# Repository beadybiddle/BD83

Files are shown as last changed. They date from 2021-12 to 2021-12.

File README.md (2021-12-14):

# BD83
A fully custom 83 Key mechanical keyboard designed around the way that I type. I intend to be able to say that this is truly a keyboard customized to my liking.
The original motivation behind this project was just a frustration at standard ANSI layouts. This project features custom everything, including PCB, plate, case, firmware, and eventually keycaps. Before creating anything, I initially just filmed my hands typing and gaming for an hour to figure out my own tendencies and key usage.

### Layout changes:
- Space bar is shrunk and split because nobody needs six keys' worth of real estate to hit one button.
- Backspace is shrunk because I don't intend to use it there. I've added a secondary backspace between the space bars.
- Caps lock is useless. I've removed it.
- Right shift is useless. I've removed it.
- Numpad function is incorporated into the FN layer on the lefthand side.
- Nav cluster has been moved around the arrow keys so it's easier and more intuitive to navigate code with home/end.
- F13 is now a thing because I had room for it.

### Hardware
There are three main custom hardware components to this keyboard:
- PCB, self explanatory
- Plate, the layer that the keyswitches clip into
- Case, the pieces that house the rest of the board

#### Plate
Keyboards don't necessarily need a plate, but for a myriad of reasons it made sense for me to use one. The plate is 0.06" 304 stainless steel, making it unyielding which is better for linear switch typefeel. I generated a template in swillKB then modeled the plate in Fusion360. Using the DXF exported from Fusion, I waterjet cut the plate.
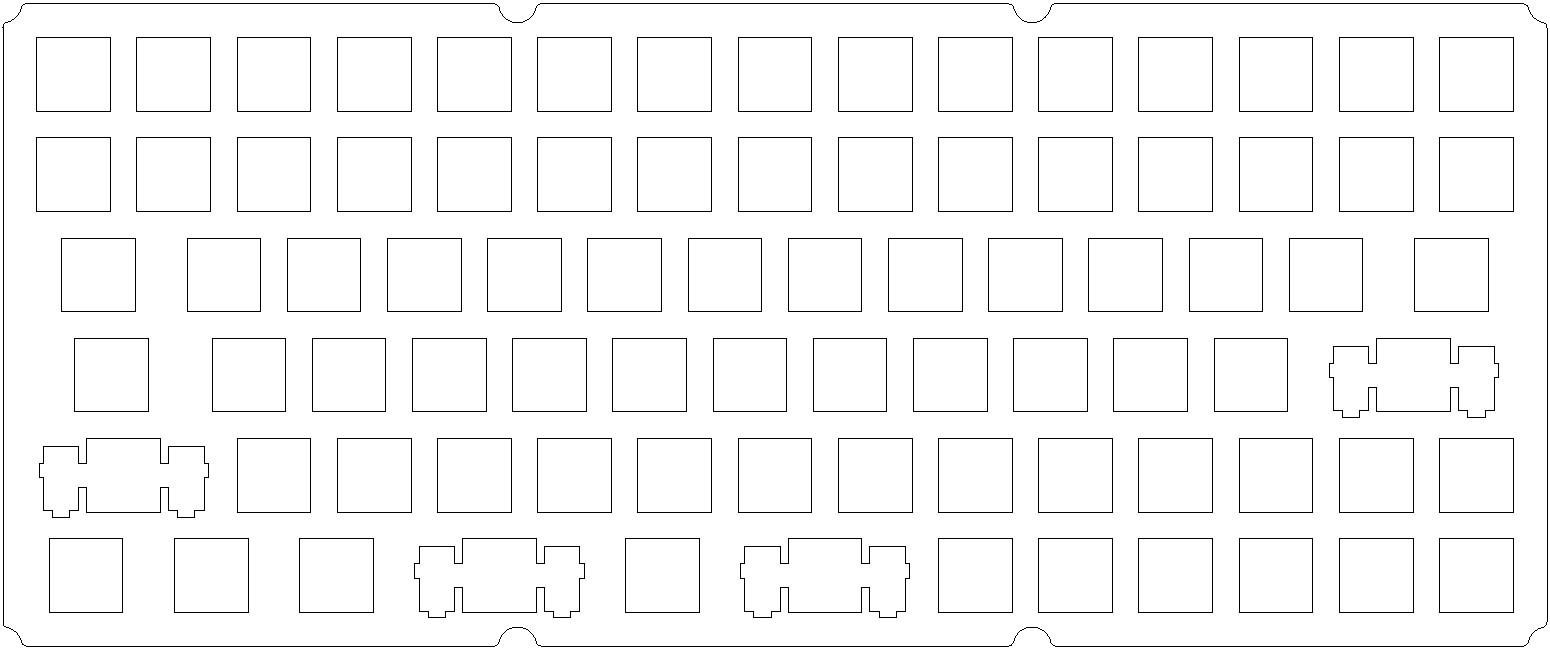
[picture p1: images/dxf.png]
DXF

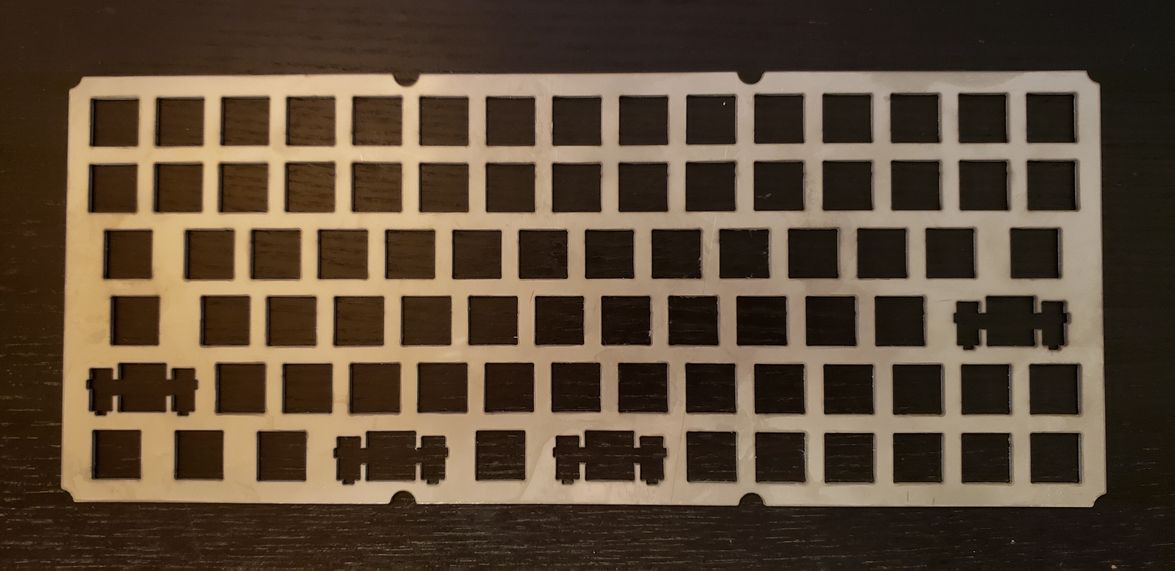
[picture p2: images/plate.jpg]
Plate


#### Case
I've designed two cases, one which is full-sized and intended to be printed on a Form 3L SLA printer at the GaTech Invention Studio, and another which is minimal (hardly qualifying as a case) that I printed on my Voxelab Aquila. All outward-facing edges are chamfered or filleted to look nice and not hurt the flesh. On the back is a hole for a USB-C adapter dongle to poke through. The underside features a pretty beadybiddle logo and some rubber feet made from EPDM rubber bands. I also designed a wrist rest to be extra, but I've made the case so slim that it's not necessary.
I was unable to get access to the Form 3L before the studio closed for the year.
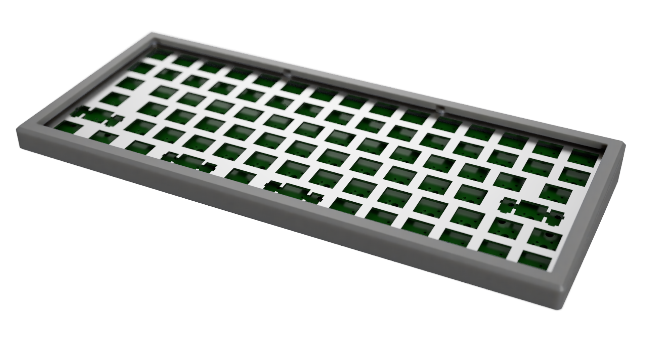
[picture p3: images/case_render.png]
Case
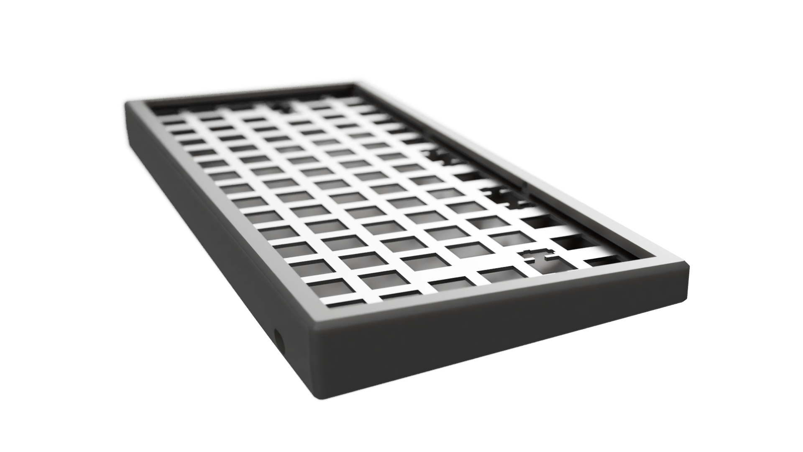
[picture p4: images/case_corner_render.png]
Case Corner
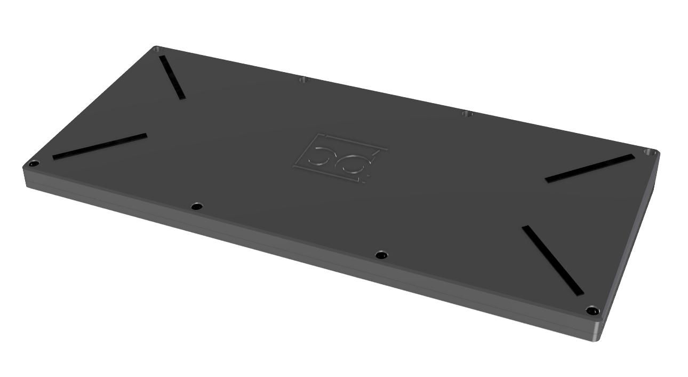
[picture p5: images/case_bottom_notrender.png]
Case Underside
  

The two halves of the case are fastened by eight M3x10 machine screws and nuts around the perimeter. The plate has flanges around the edges that allow it to be sandwiched between these two halves, cushioned by strips of EPDM to dampen the sound and make the typefeel just a little springy. The interior of the case has only 0.8mm of wiggle room to the dangling PCB, making it literally as compact as possible. It is angled five degrees so that the front height is minimized while making room for the Feather board and batteries in the back.
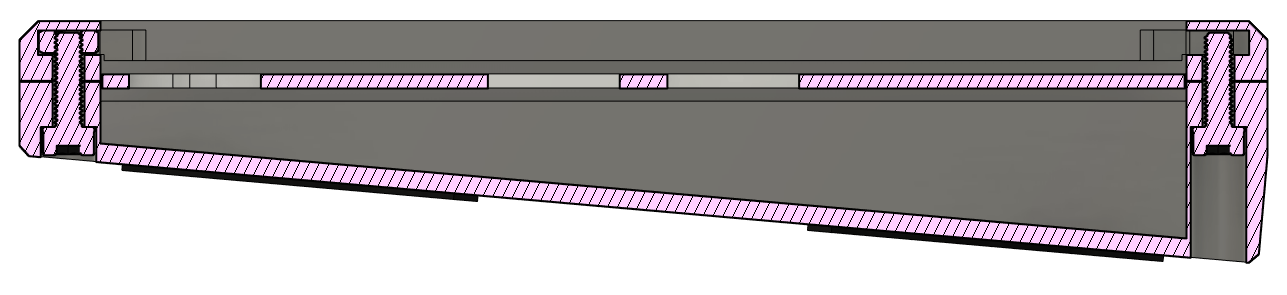
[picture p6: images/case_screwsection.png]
Fastener Assembly
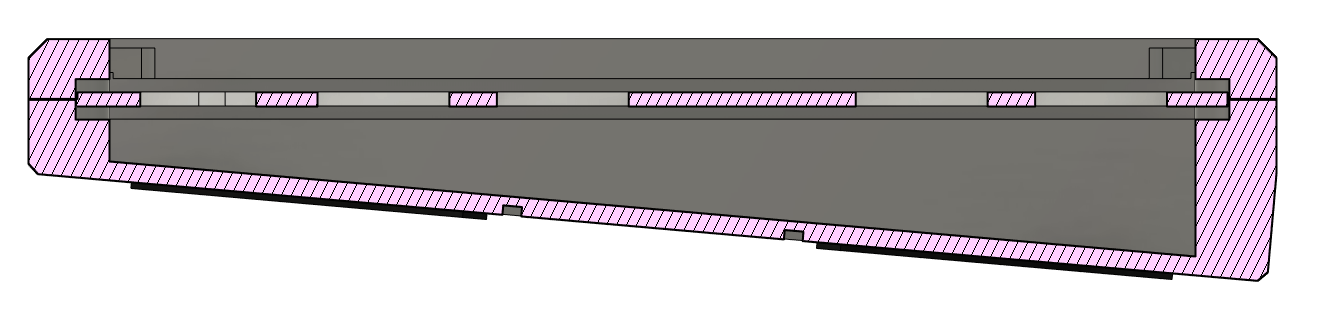
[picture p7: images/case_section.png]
Plate Sandwich
 

The minimal "case" is actually four feet that clip onto the plate and are secured by a single large band. It has the same five degree inclination as the full case so that the electronics won't touch the desk surface. The open design leaves the switches and PCB accessible.
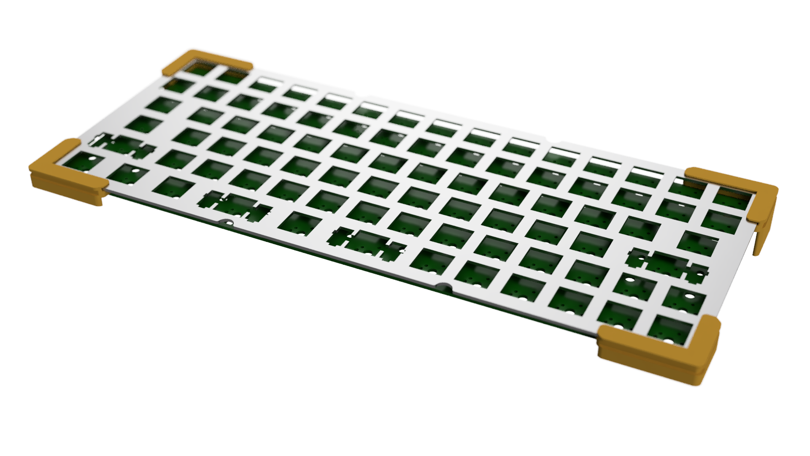
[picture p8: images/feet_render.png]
Feet


#### PCB
The PCB took the longest of all the components (maybe because I'd never made one before) but I'll try to keep it brief here:
I made it to support three main features: bluetooth, RGB lighting, and some level of expandability.
The brains of the board is an Adafruit Feather 32u4 Bluefruit LE, which is a devboard with an intregated nRF51822 BLE module. It also handles LiPo power for going completely wireless.
The LEDs are common-anode RGB packages, and are controlled by two IS31FL3733B drivers. The MCU talks to these drivers via I2C. I was originally planning to use a string of WS2812Bs or SK6812Es, but these have a substantially higher power draw than the ISSI scanning matrix drivers.
There are only 20 GPIO pins on the Feather, though, and several are already used for SPI with the BLE module. In order to accomodate my ideal 83 keys, it would take at least 19 pins to connect all the switches even with matrix duplexing, a number that I couldn't muster while dedicating three to the LED drivers. To get get some extra GPIO, I use an MCP23017 I2C I/O expander. This communicates on the same I2C lines as the ISSI drivers, and creates an additional 16 GPIO pins - more than enough for the rest of the switch matrix.

Diodes are placed between each switch and its corresponding row to prevent ghosting as the matrix is scanned.
VCC is fed through decoupling caps as needed to the slave chips; decoupling around the MCU is already handled by the Feather board.
The address pins on the three I2C chips have solder bridges for customizing the addresses if more devices are added.
A SPDT switch controls the 3V3 regulator enable pin so that power can be controlled, especially when going wireless.
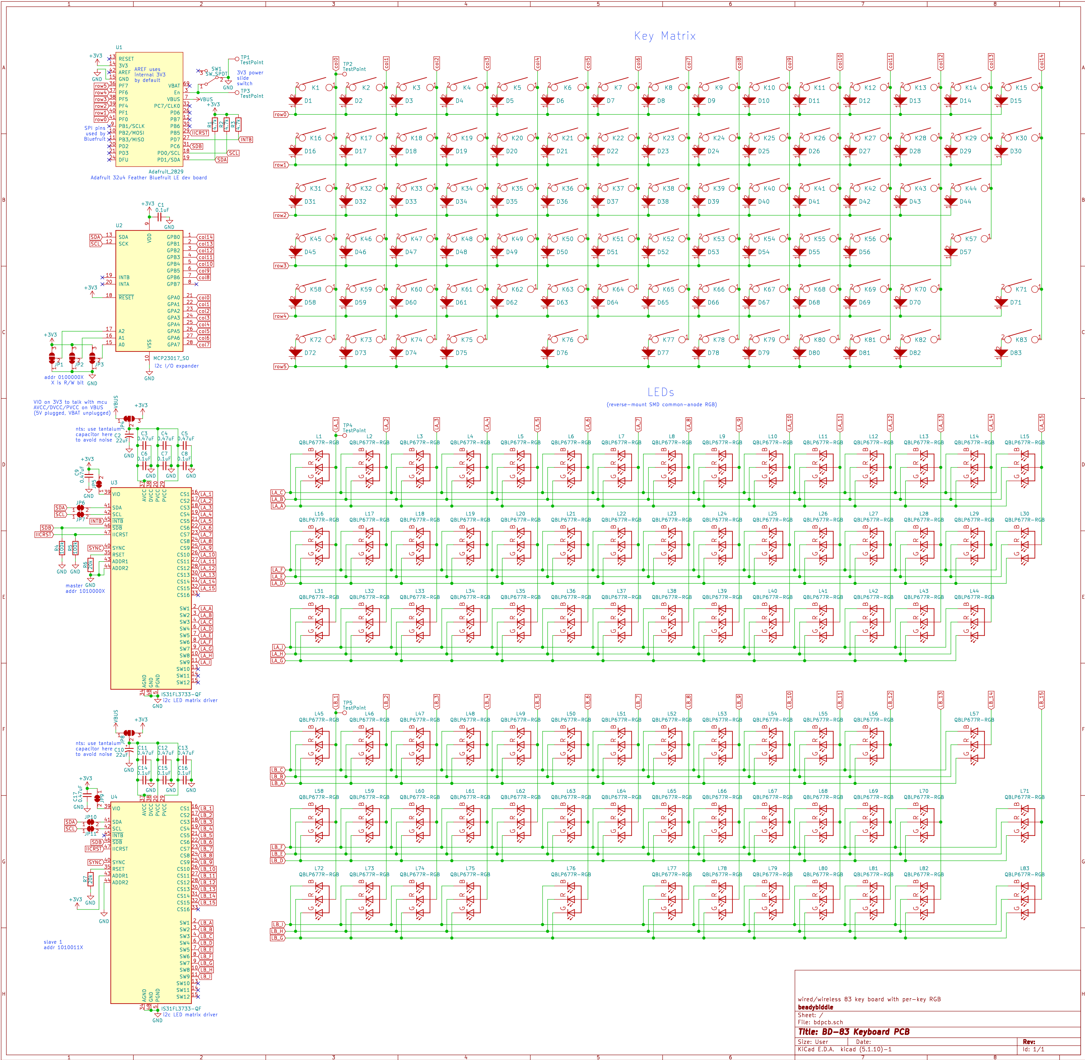
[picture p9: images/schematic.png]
Schematic


The PCB was definitely the most fun part of this whole project; learning to make something so different from what I'm used to was nice.
I routed all of the traces twice because after getting an understanding and making some messy paths the first time it was much easier to organize the rats nest from scratch.
I also went through several iterations of component placements in the process in order to make room for the traces and switches. Most keyboards have plenty of free real estate behind their big spacebars or above the arrow keys, but my compact layout meant everything had to be crammed in tight gaps.
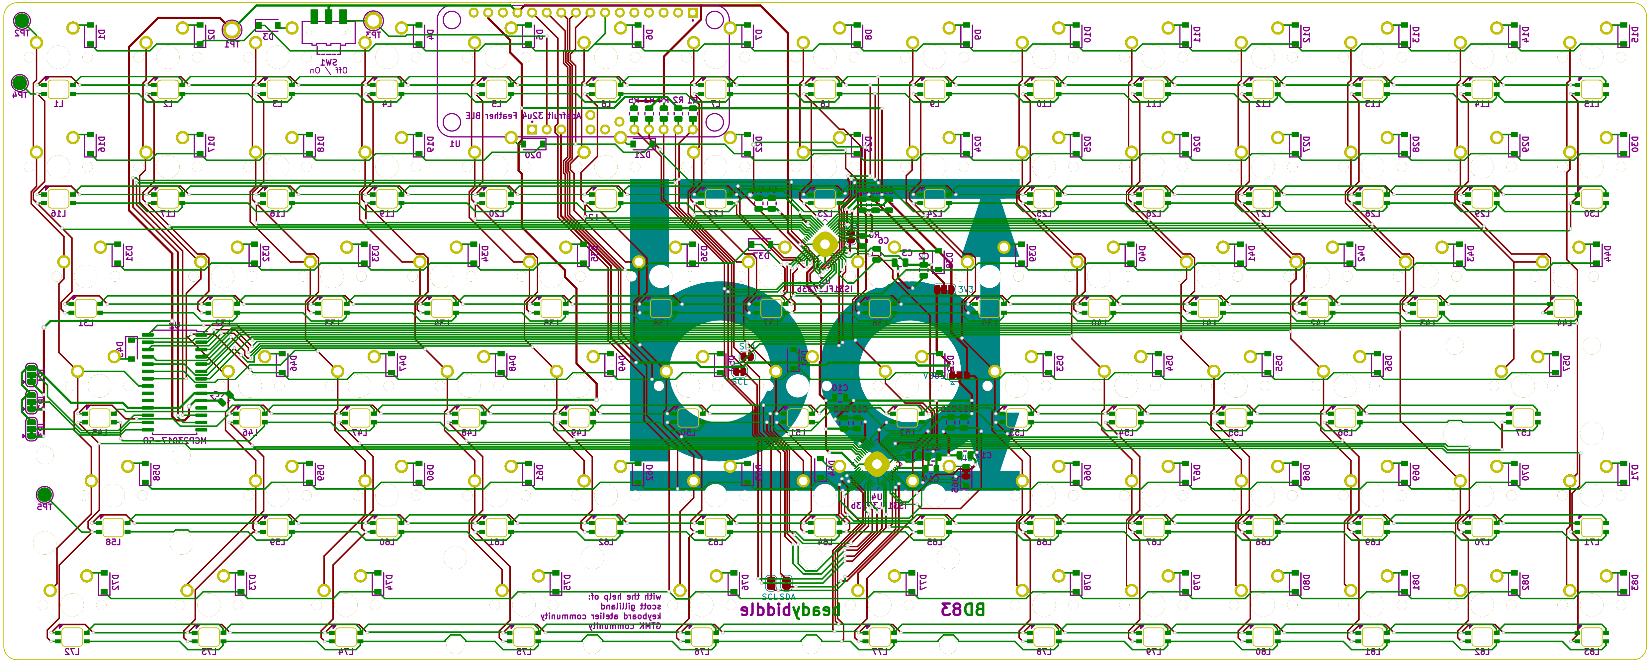
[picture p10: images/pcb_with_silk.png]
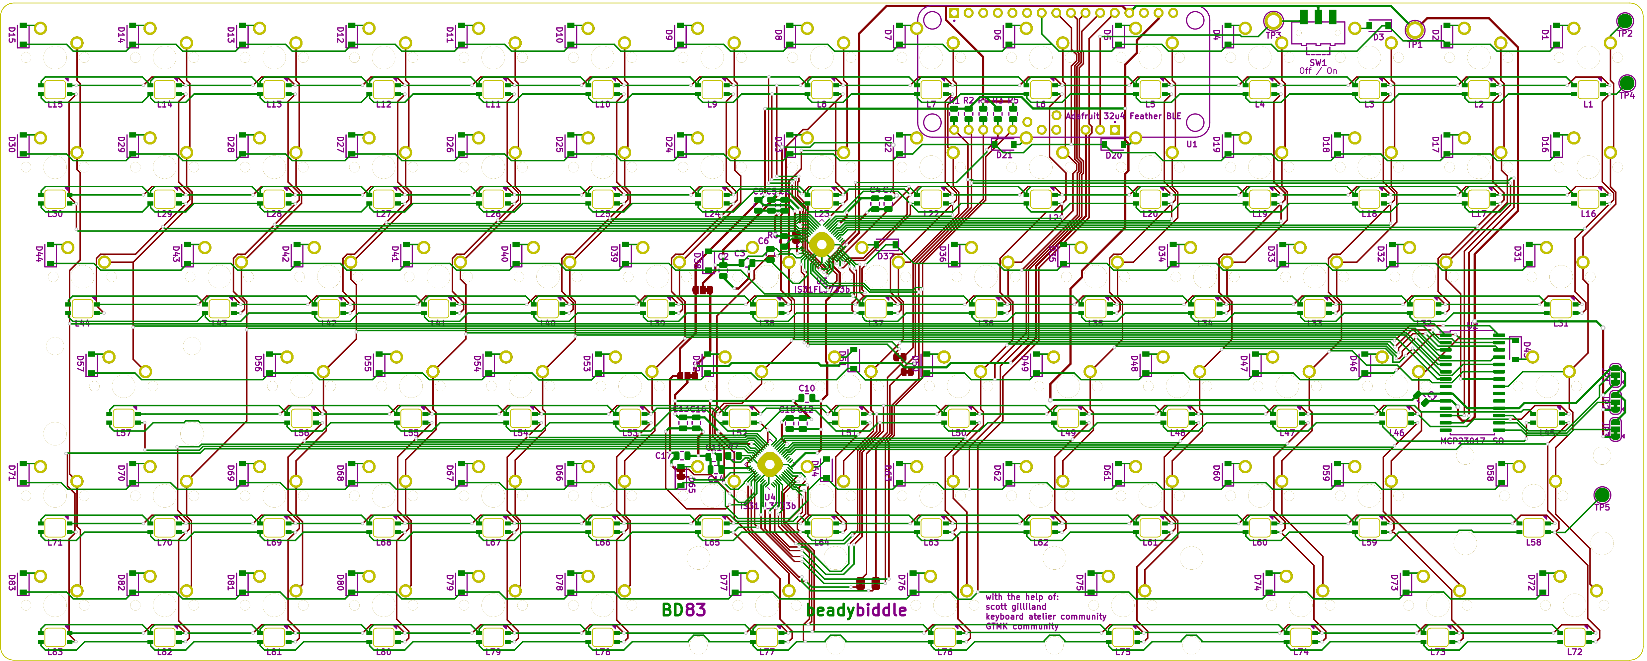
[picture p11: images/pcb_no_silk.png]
 
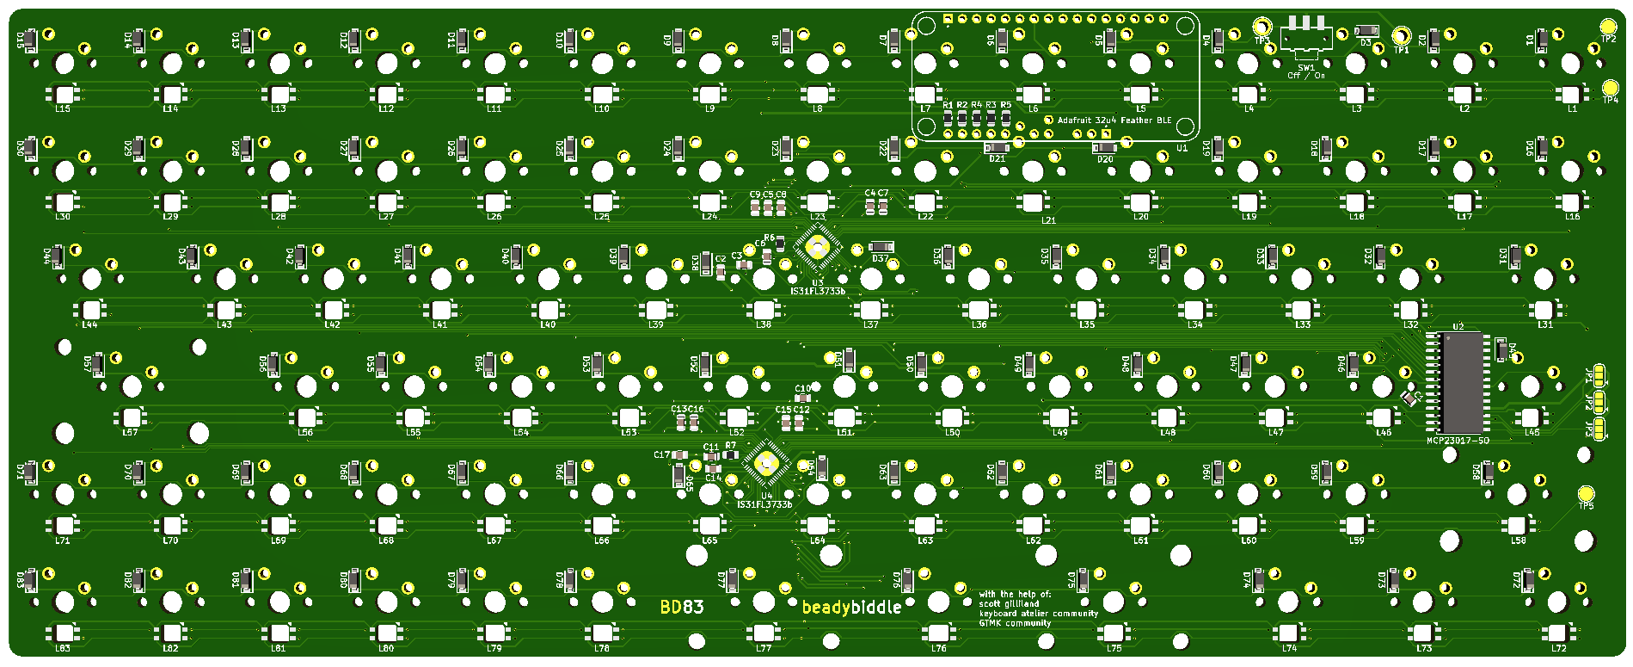
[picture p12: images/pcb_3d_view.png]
PCB Render


This was also the first time I'd done reflow soldering, but that was easy enough with the stencil and oven. And only one diode was backwards!
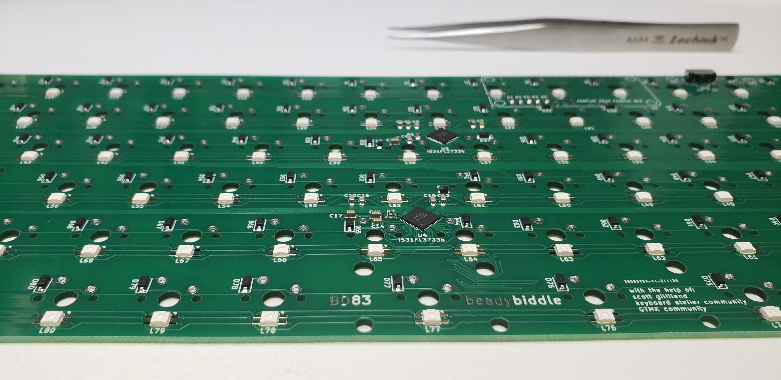
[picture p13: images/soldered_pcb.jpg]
PCB Photo

Designed in KiCad and fabricated by JLCPCB.

### Firmware
Easily the most difficult (or maybe just frustrating?) part, I wrote custom firmware for the board with the help of the QMK framework. QMK handles a lot of the nitty gritty stuff so that I instead dedicate dozens of hours to custom matrix scanning and debugging the RGB.
Defining switch order, keymappings, and LED positions was tedious but simple. The real problem was that as far as I can tell, I'm the first person to make a keyboard that drives rows from the MCU and read columns from an IO expander.
I visited square one a few times, rewriting the firmware each time I ran into a deadend that couldn't be debugged.
The first time, I thought the board wasn't flashing. Turns out it was flashing, but the firmware I wrote sucked so bad that it kicked back into bootloader.
The second time, I had it flashed but nothing responded and no debug messages even printed. I never figured out why, because I just rewrote everything after a day of failed debugging.
Finally I have the (mostly) working firmware, which is fully functional as a keyboard input and also supports typing over bluetooth. Unfortunately the RGB still doesn't work for some unknown reason, but luckily the BLE meets the critera for additional features to the keyboard.

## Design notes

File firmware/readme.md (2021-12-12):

# bd83

bd83

83 Key Keeb.
Adafruit Feather 32u4 BLE dev board, MCP23017 I2C expander to make enough GPIO, two IS31FL3733Bs for driving per-key RGB.

* Keyboard Maintainer: [beadybiddle](https://github.com/beadybiddle)
* Hardware Supported: Custom PCB
* Hardware Availability: TODO fetch links to components

Make example for this keyboard (after setting up your build environment):

    make bd83:default

Flashing example for this keyboard:

    make bd83:default:flash

See the [build environment setup](https://docs.qmk.fm/#/getting_started_build_tools) and the [make instructions](https://docs.qmk.fm/#/getting_started_make_guide) for more information. Brand new to QMK? Start with our [Complete Newbs Guide](https://docs.qmk.fm/#/newbs).

## Bootloader

Enter the bootloader in 3 ways:

* **Bootmagic reset**: Hold down `ESC` and plug in the keyboard
* **Physical reset button**: Briefly press the button on the Feather Dev Board
* **Keycode in layout**: Press `FN+RESET`

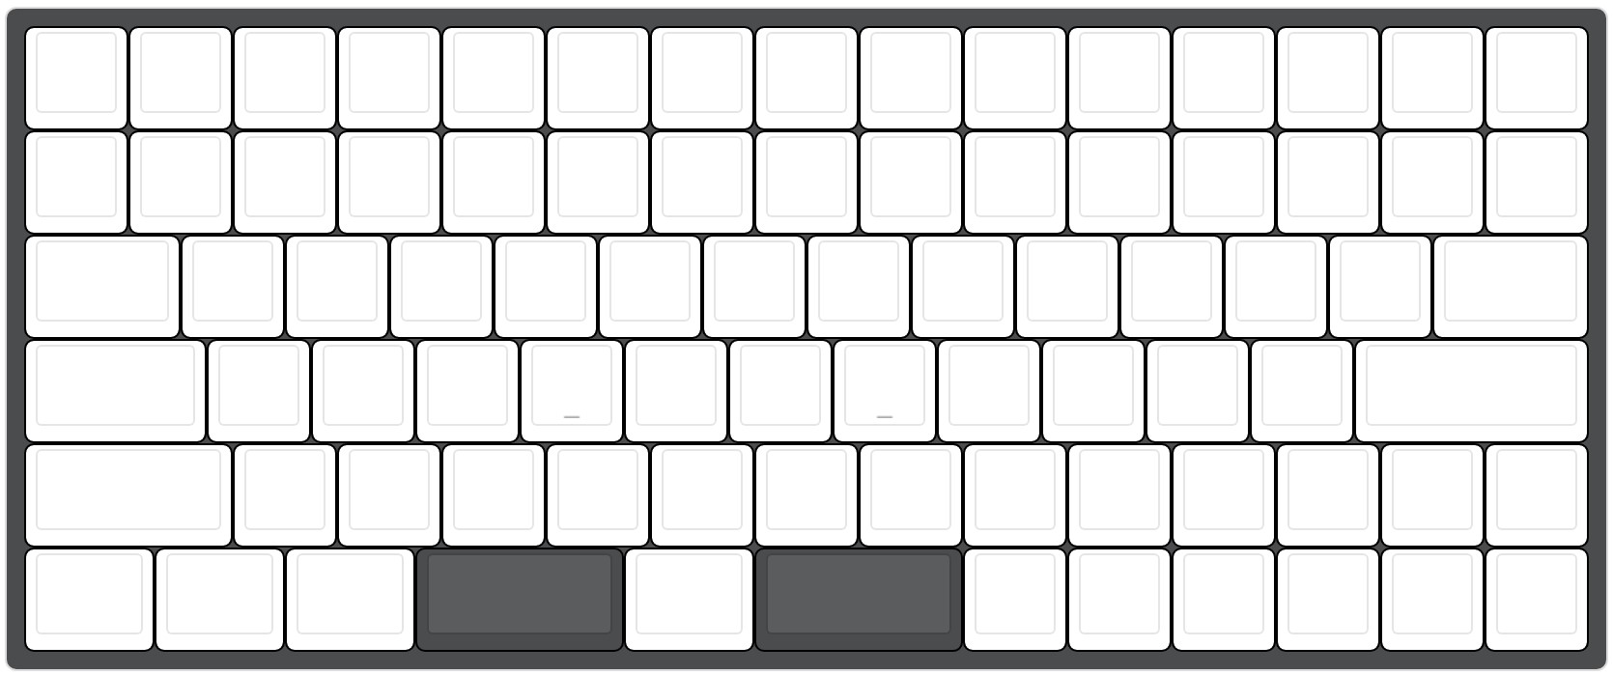
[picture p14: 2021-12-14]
images/bd-83-palette.jpg

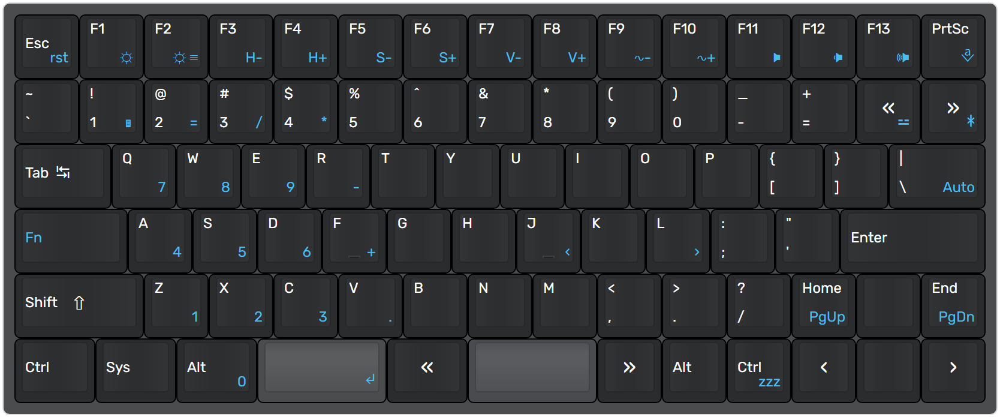
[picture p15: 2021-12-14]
images/bd-83_legended.png

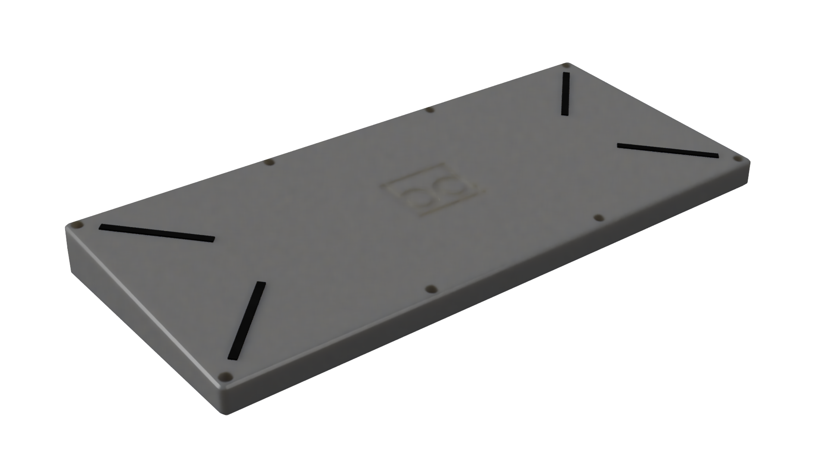
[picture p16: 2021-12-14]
images/case_bottom_render.png

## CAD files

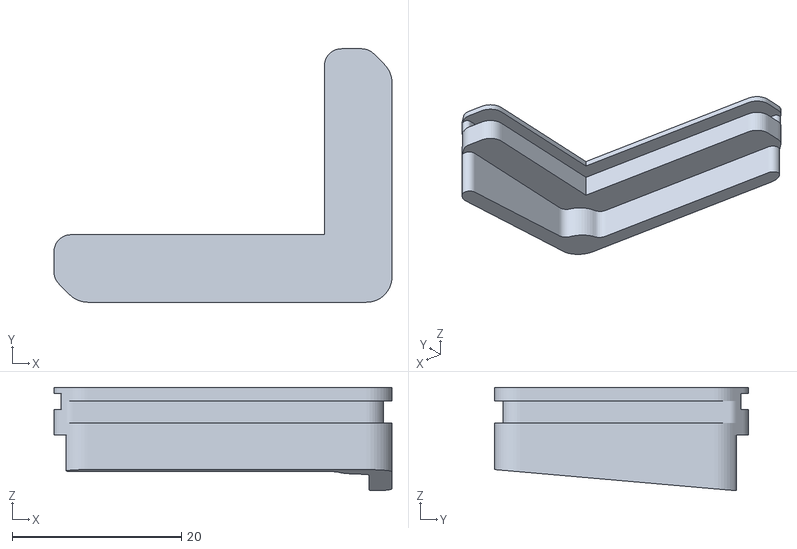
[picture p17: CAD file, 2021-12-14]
models/foot_BR.stl
40.0 x 30.0 x 12.2

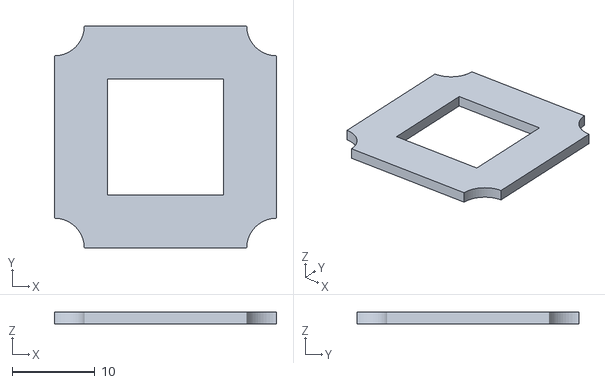
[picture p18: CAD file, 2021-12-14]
models/sample plate.stl
26.9 x 26.9 x 1.50

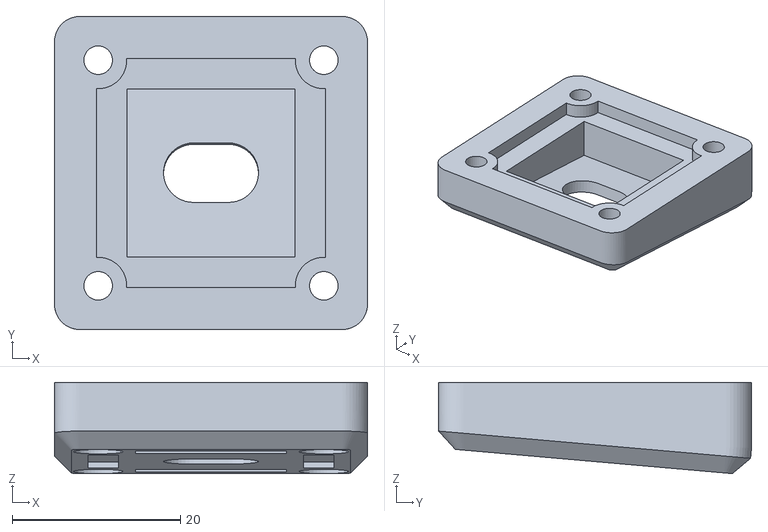
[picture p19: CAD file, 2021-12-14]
models/sample base.stl
37.3 x 37.3 x 10.9

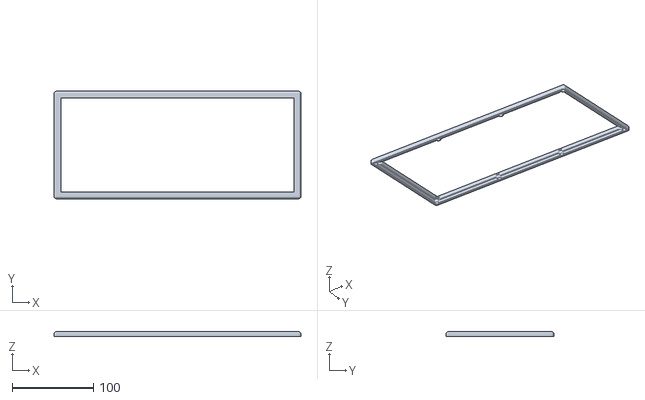
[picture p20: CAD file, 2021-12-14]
models/top.stl
304.0 x 132.5 x 6.35

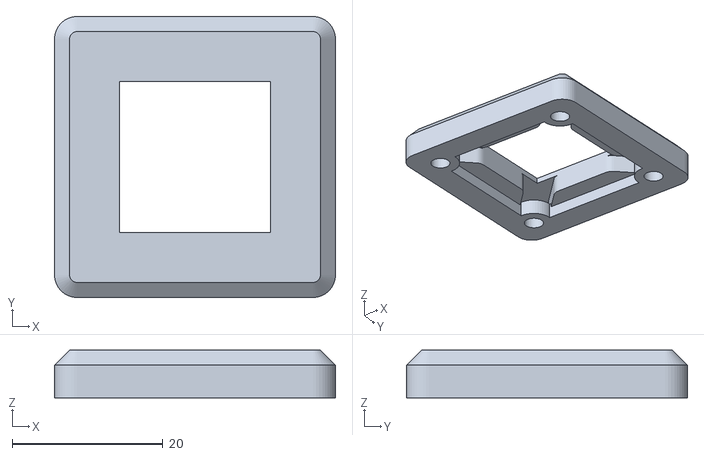
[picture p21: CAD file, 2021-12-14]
models/sample top.stl
37.3 x 37.3 x 6.35

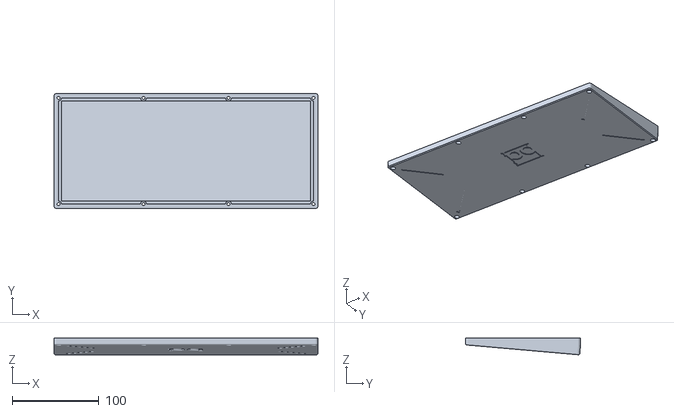
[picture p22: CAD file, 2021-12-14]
models/base.stl
304.0 x 132.5 x 19.2

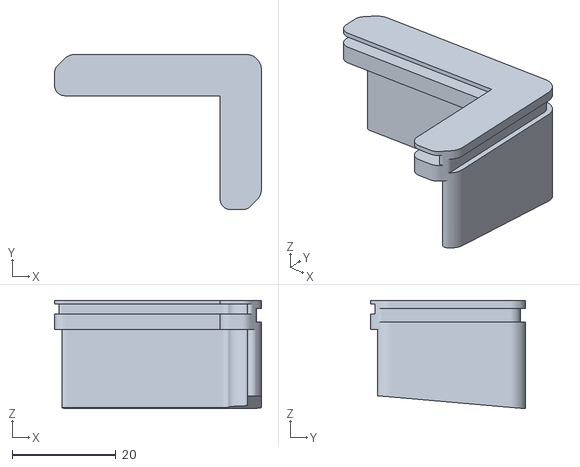
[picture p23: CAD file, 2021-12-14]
models/foot_TR.stl
40.0 x 30.0 x 20.9

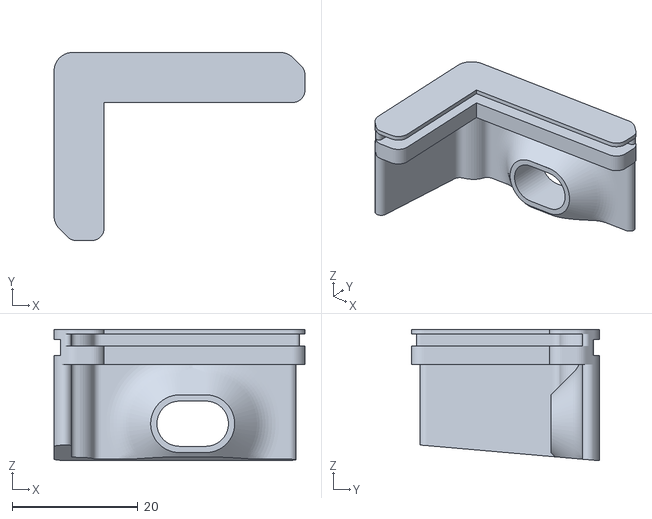
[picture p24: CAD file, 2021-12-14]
models/foot_TL.stl
40.0 x 30.0 x 20.9

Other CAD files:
models/foot_BL.stl

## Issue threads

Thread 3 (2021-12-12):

3V3 regulator enable switch interferes with cable

beadybiddle, 2021-12-12:
the SMD SPDT switch used for disabling the 3V3 power blocks most micro-USB cables going into the Feather

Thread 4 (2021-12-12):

space stabilizers cutouts on plate should be reversed

beadybiddle, 2021-12-12:
they are reversed on the PCB but not the plate

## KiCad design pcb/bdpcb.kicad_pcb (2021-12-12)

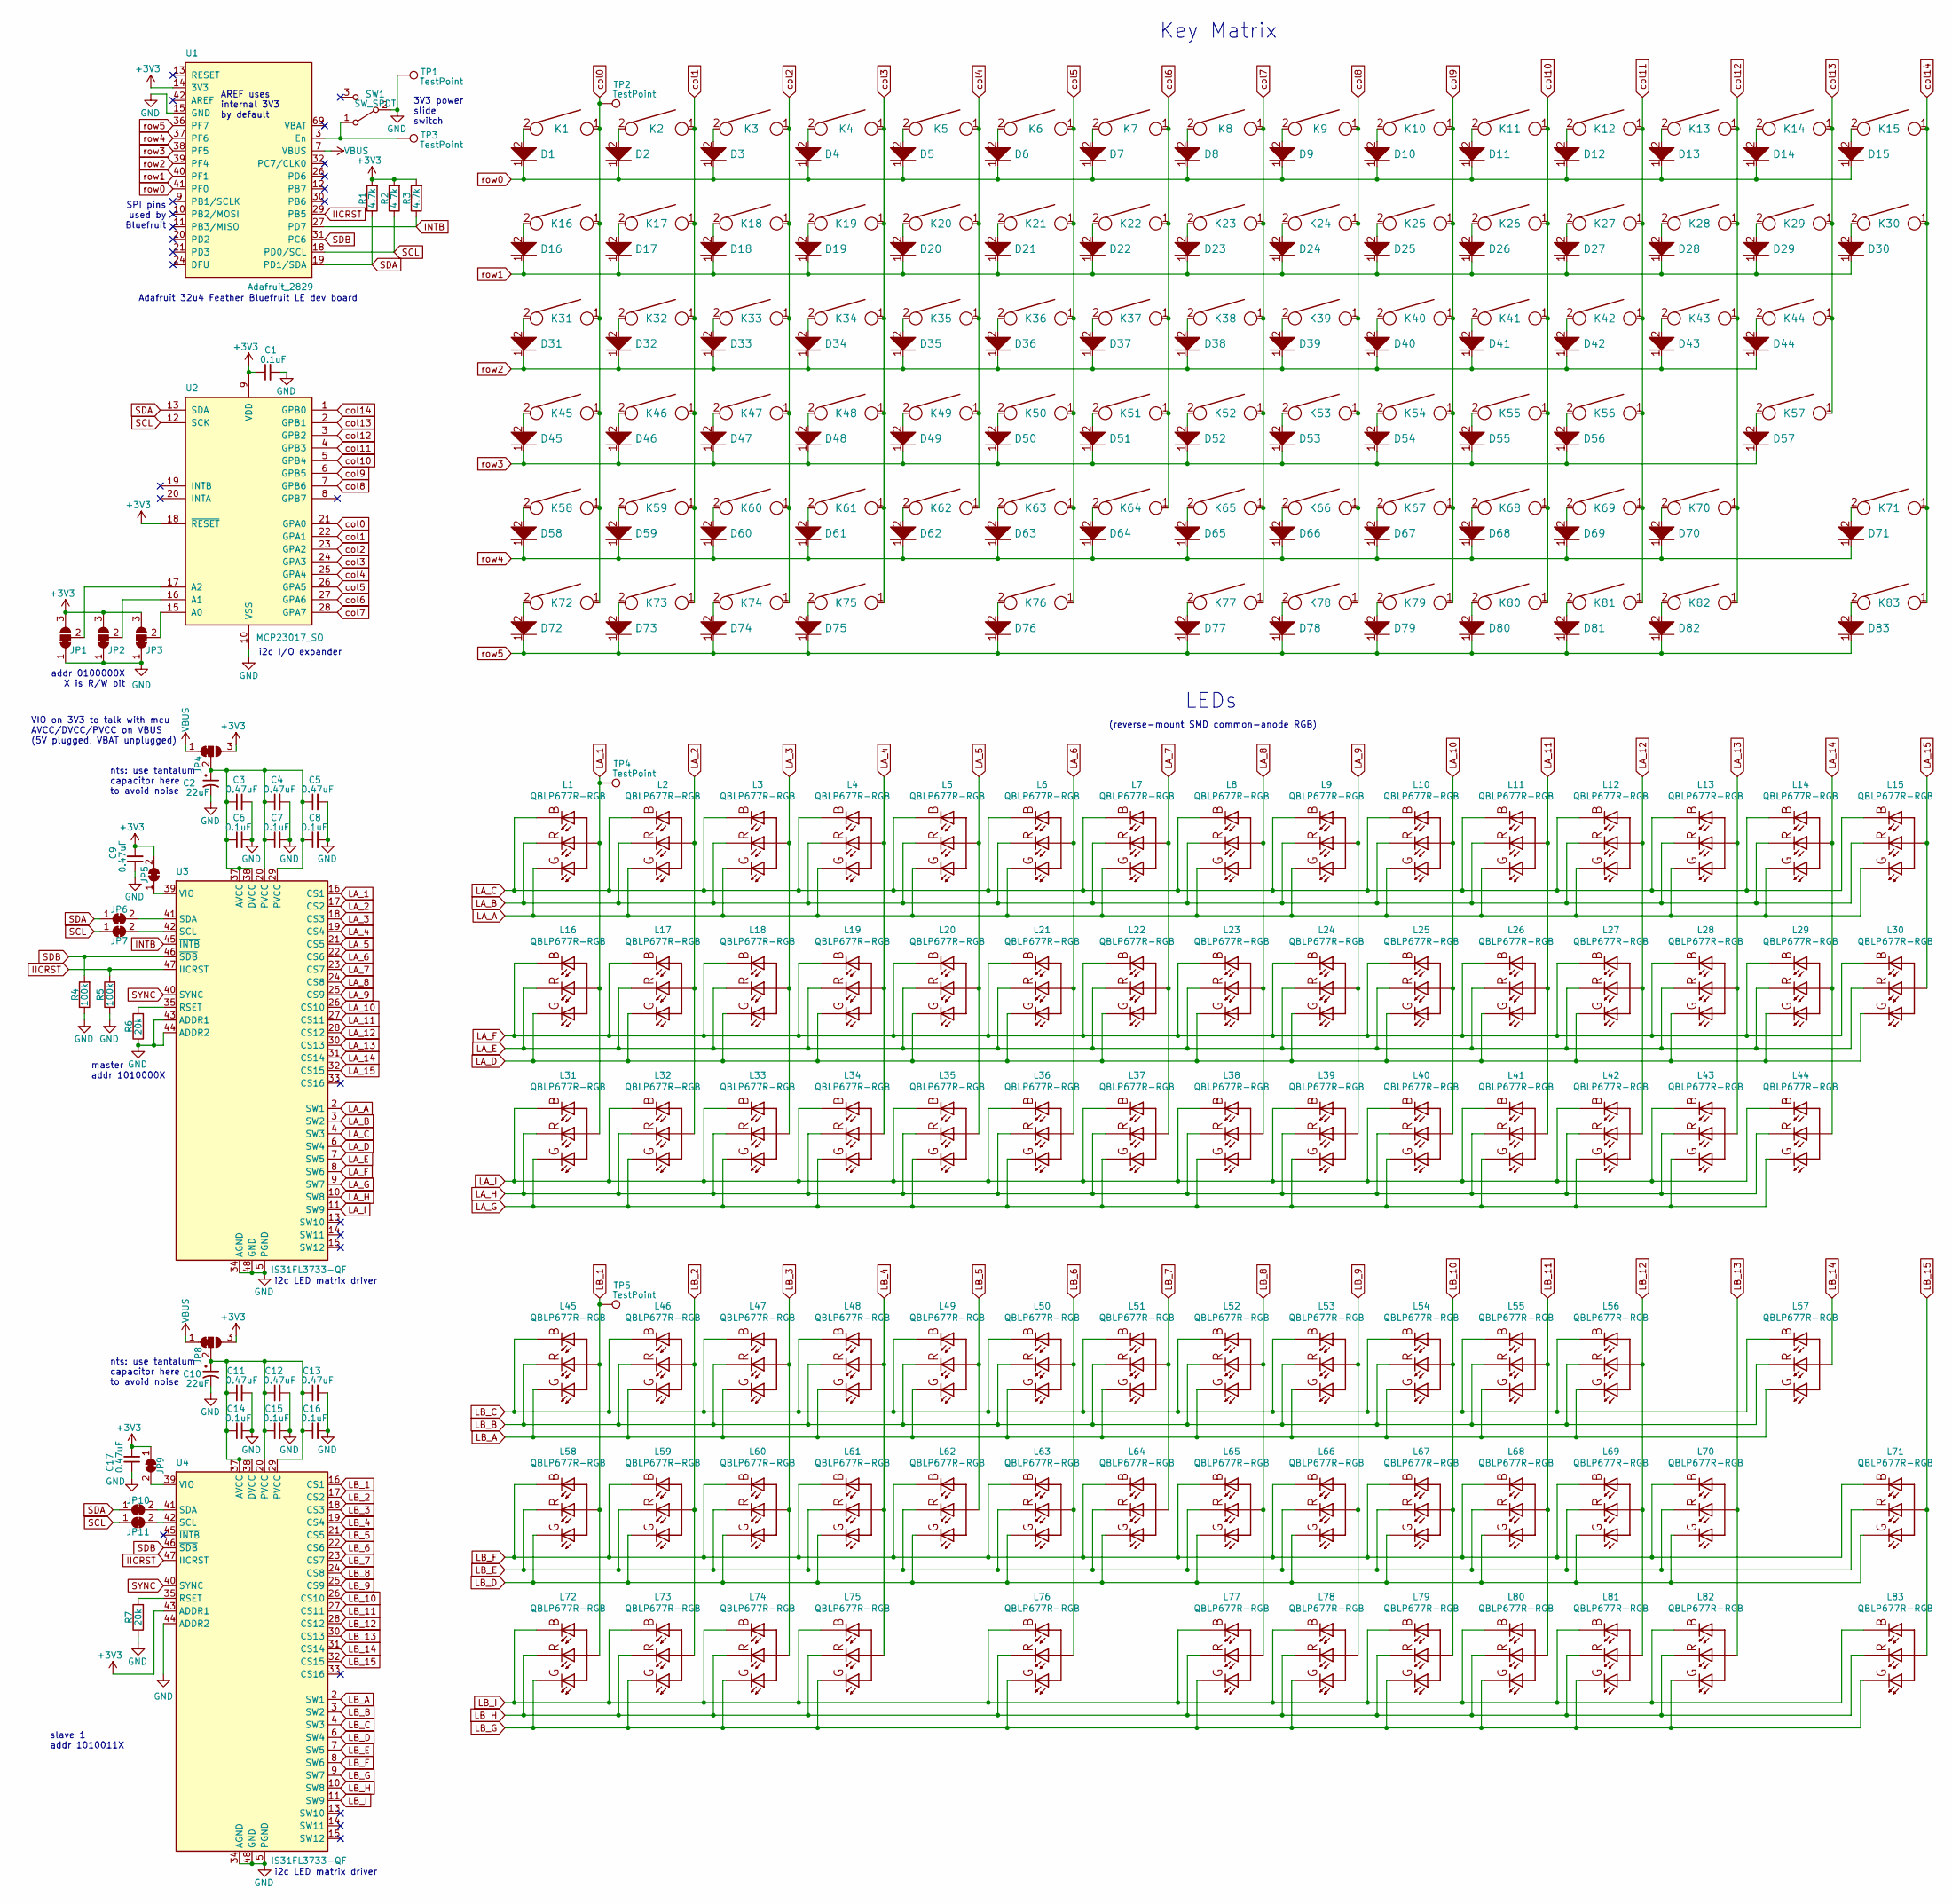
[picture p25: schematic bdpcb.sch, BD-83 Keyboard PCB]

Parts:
C1, C6, C7, C8, C14, C15, C16: 0.1uF; C_0805_2012Metric
C2, C10: 22uF; C_0805_2012Metric
C3, C4, C5, C9, C11, C12, C13, C17: 0.47uF; C_0805_2012Metric
D1, D2, D3, D4, D5, D6, D7, D8, D9, D10, D11, D12, D13, D14, D15, D16, D17, D18, D19, D20, D21, D22, D23, D24, D25, D26, D27, D28, D29, D30, D31, D32, D33, D34, D35, D36, D37, D38, D39, D40, D41, D42, D43, D44, D45, D46, D47, D48, D49, D50, D51, D52, D53, D54, D55, D56, D57, D58, D59, D60, D61, D62, D63, D64, D65, D66, D67, D68, D69, D70, D71, D72, D73, D74, D75, D76, D77, D78, D79, D80, D81, D82, D83: D; D_SOD-123
JP1, JP2, JP3, JP4, JP8: 13_bridge; SolderJumper-3_P1.3mm_Bridged12_RoundedPad1.0x1.5mm
JP5, JP6, JP7, JP9, JP10, JP11: SolderJumper_2_Bridged; SolderJumper-2_P1.3mm_Bridged_RoundedPad1.0x1.5mm
K1, K2, K3, K4, K5, K6, K7, K8, K9, K10, K11, K12, K13, K14, K15, K16, K17, K18, K19, K20, K21, K22, K23, K24, K25, K26, K27, K28, K29, K30, K32, K33, K34, K35, K36, K37, K38, K39, K40, K41, K42, K43, K46, K47, K48, K49, K50, K51, K52, K53, K54, K55, K56, K59, K60, K61, K62, K63, K64, K65, K66, K67, K68, K69, K70, K71, K76, K78, K79, K80, K81, K82, K83: KEYSW; MXOnly-1U-NoLED
K31, K44: KEYSW; MXOnly-1.5U-NoLED
K45: KEYSW; MXOnly-1.75U-NoLED
K57: KEYSW; MXOnly-2.25U-NoLED
K58: KEYSW; MXOnly-2U-NoLED
K72, K73, K74: KEYSW; MXOnly-1.25U-NoLED
K75, K77: KEYSW; MXOnly-2U-ReversedStabilizers-NoLED
L1, L2, L3, L4, L5, L6, L7, L8, L9, L10, L11, L12, L13, L14, L15, L16, L17, L18, L19, L20, L21, L22, L23, L24, L25, L26, L27, L28, L29, L30, L31, L32, L33, L34, L35, L36, L37, L38, L39, L40, L41, L42, L43, L44, L45, L46, L47, L48, L49, L50, L51, L52, L53, L54, L55, L56, L57, L58, L59, L60, L61, L62, L63, L64, L65, L66, L67, L68, L69, L70, L71, L72, L73, L74, L75, L76, L77, L78, L79, L80, L81, L82, L83: QBLP677R-RGB; RGB-REVERSE_MOUNT
R1, R2, R3: 4.7k; R_0805_2012Metric
R4, R5: 100k; R_0805_2012Metric
R6, R7: 20k; R_0805_2012Metric
SW1: SW_SPDT; SW_SPDT_CK-JS102011SAQN
TP1, TP3: TestPoint; TestPoint_Plated_Hole_D2.0mm
TP2, TP4, TP5: TestPoint; TestPoint_Pad_D2.5mm
U1: Adafruit_2829; ADAFRUIT_2829
U2: MCP23017_SO; SOIC-28W_7.5x17.9mm_P1.27mm
U3, U4: IS31FL3733-QF; QFN-48-1EP_6x6mm_P0.4mm_EP4.2x4.2mm

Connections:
+3V3: C1.1, C9.2, C17.2, JP1.3 (B), JP2.3 (B), JP3.3 (B), JP4.3 (B), JP5.2 (B), JP8.3 (B), JP9.1 (A), R1.2, R2.2, R3.2, U1.14 (3V3), U2.9 (VDD), U2.18 (~RESET~), U4.43 (ADDR1); also elsewhere on the board
GND: C1.2, C2.2, C3.2, C4.2, C5.2, C6.2, C7.2, C8.2, C9.1, C10.2, C11.2, C12.2, C13.2, C14.2, C15.2, C16.2, C17.1, JP1.1 (A), JP2.1 (A), JP3.1 (A), R4.1, R5.1, R6.1, R7.1, SW1.2 (B), TP1.1, U1.15 (GND), U2.10 (VSS), U3.5 (PGND), U3.12 (PGND), U3.34 (AGND), U3.43 (ADDR1), U3.44 (ADDR2), U3.48 (GND), U3.49 (GND), U4.5 (PGND), U4.12 (PGND), U4.34 (AGND), U4.44 (ADDR2), U4.48 (GND), U4.49 (GND)
IICRST: R5.2, U1.29 (PB5), U3.47 (IICRST), U4.47 (IICRST)
INTB: R3.1, U1.27 (PD7), U3.45 (~INTB)
LA_1: L1.COMMON_ANODE, L16.COMMON_ANODE, L31.COMMON_ANODE, TP4.1, U3.16 (CS1)
LA_2: L2.COMMON_ANODE, L17.COMMON_ANODE, L32.COMMON_ANODE, U3.17 (CS2)
LA_3: L3.COMMON_ANODE, L18.COMMON_ANODE, L33.COMMON_ANODE, U3.18 (CS3)
LA_4: L4.COMMON_ANODE, L19.COMMON_ANODE, L34.COMMON_ANODE, U3.19 (CS4)
LA_5: L5.COMMON_ANODE, L20.COMMON_ANODE, L35.COMMON_ANODE, U3.21 (CS5)
LA_6: L6.COMMON_ANODE, L21.COMMON_ANODE, L36.COMMON_ANODE, U3.22 (CS6)
LA_7: L7.COMMON_ANODE, L22.COMMON_ANODE, L37.COMMON_ANODE, U3.23 (CS7)
LA_8: L8.COMMON_ANODE, L23.COMMON_ANODE, L38.COMMON_ANODE, U3.24 (CS8)
LA_9: L9.COMMON_ANODE, L24.COMMON_ANODE, L39.COMMON_ANODE, U3.25 (CS9)
LA_10: L10.COMMON_ANODE, L25.COMMON_ANODE, L40.COMMON_ANODE, U3.26 (CS10)
LA_11: L11.COMMON_ANODE, L26.COMMON_ANODE, L41.COMMON_ANODE, U3.27 (CS11)
LA_12: L12.COMMON_ANODE, L27.COMMON_ANODE, L42.COMMON_ANODE, U3.28 (CS12)
LA_13: L13.COMMON_ANODE, L28.COMMON_ANODE, L43.COMMON_ANODE, U3.30 (CS13)
LA_14: L14.COMMON_ANODE, L29.COMMON_ANODE, L44.COMMON_ANODE, U3.31 (CS14)
LA_15: L15.COMMON_ANODE, L30.COMMON_ANODE, U3.32 (CS15)
LA_A: L1.2, L2.2, L3.2, L4.2, L5.2, L6.2, L7.2, L8.2, L9.2, L10.2, L11.2, L12.2, L13.2, L14.2, L15.2, U3.2 (SW1)
LA_B: L1.3, L2.3, L3.3, L4.3, L5.3, L6.3, L7.3, L8.3, L9.3, L10.3, L11.3, L12.3, L13.3, L14.3, L15.3, U3.3 (SW2)
LA_C: L1.1, L2.1, L3.1, L4.1, L5.1, L6.1, L7.1, L8.1, L9.1, L10.1, L11.1, L12.1, L13.1, L14.1, L15.1, U3.4 (SW3)
LA_D: L16.2, L17.2, L18.2, L19.2, L20.2, L21.2, L22.2, L23.2, L24.2, L25.2, L26.2, L27.2, L28.2, L29.2, L30.2, U3.6 (SW4)
LA_E: L16.3, L17.3, L18.3, L19.3, L20.3, L21.3, L22.3, L23.3, L24.3, L25.3, L26.3, L27.3, L28.3, L29.3, L30.3, U3.7 (SW5)
LA_F: L16.1, L17.1, L18.1, L19.1, L20.1, L21.1, L22.1, L23.1, L24.1, L25.1, L26.1, L27.1, L28.1, L29.1, L30.1, U3.8 (SW6)
LA_G: L31.2, L32.2, L33.2, L34.2, L35.2, L36.2, L37.2, L38.2, L39.2, L40.2, L41.2, L42.2, L43.2, L44.2, U3.9 (SW7)
LA_H: L31.3, L32.3, L33.3, L34.3, L35.3, L36.3, L37.3, L38.3, L39.3, L40.3, L41.3, L42.3, L43.3, L44.3, U3.10 (SW8)
LA_I: L31.1, L32.1, L33.1, L34.1, L35.1, L36.1, L37.1, L38.1, L39.1, L40.1, L41.1, L42.1, L43.1, L44.1, U3.11 (SW9)
LB_1: L45.COMMON_ANODE, L58.COMMON_ANODE, L72.COMMON_ANODE, TP5.1, U4.16 (CS1)
LB_2: L46.COMMON_ANODE, L59.COMMON_ANODE, L73.COMMON_ANODE, U4.17 (CS2)
LB_3: L47.COMMON_ANODE, L60.COMMON_ANODE, L74.COMMON_ANODE, U4.18 (CS3)
LB_4: L48.COMMON_ANODE, L61.COMMON_ANODE, L75.COMMON_ANODE, U4.19 (CS4)
LB_5: L49.COMMON_ANODE, L62.COMMON_ANODE, U4.21 (CS5)
LB_6: L50.COMMON_ANODE, L63.COMMON_ANODE, L76.COMMON_ANODE, U4.22 (CS6)
LB_7: L51.COMMON_ANODE, L64.COMMON_ANODE, U4.23 (CS7)
LB_8: L52.COMMON_ANODE, L65.COMMON_ANODE, L77.COMMON_ANODE, U4.24 (CS8)
LB_9: L53.COMMON_ANODE, L66.COMMON_ANODE, L78.COMMON_ANODE, U4.25 (CS9)
LB_10: L54.COMMON_ANODE, L67.COMMON_ANODE, L79.COMMON_ANODE, U4.26 (CS10)
LB_11: L55.COMMON_ANODE, L68.COMMON_ANODE, L80.COMMON_ANODE, U4.27 (CS11)
LB_12: L56.COMMON_ANODE, L69.COMMON_ANODE, L81.COMMON_ANODE, U4.28 (CS12)
LB_13: L70.COMMON_ANODE, L82.COMMON_ANODE, U4.30 (CS13)
LB_14: L57.COMMON_ANODE, U4.31 (CS14)
LB_15: L71.COMMON_ANODE, L83.COMMON_ANODE, U4.32 (CS15)
LB_A: L45.2, L46.2, L47.2, L48.2, L49.2, L50.2, L51.2, L52.2, L53.2, L54.2, L55.2, L56.2, L57.2, U4.2 (SW1)
LB_B: L45.3, L46.3, L47.3, L48.3, L49.3, L50.3, L51.3, L52.3, L53.3, L54.3, L55.3, L56.3, L57.3, U4.3 (SW2)
LB_C: L45.1, L46.1, L47.1, L48.1, L49.1, L50.1, L51.1, L52.1, L53.1, L54.1, L55.1, L56.1, L57.1, U4.4 (SW3)
LB_D: L58.2, L59.2, L60.2, L61.2, L62.2, L63.2, L64.2, L65.2, L66.2, L67.2, L68.2, L69.2, L70.2, L71.2, U4.6 (SW4)
LB_E: L58.3, L59.3, L60.3, L61.3, L62.3, L63.3, L64.3, L65.3, L66.3, L67.3, L68.3, L69.3, L70.3, L71.3, U4.7 (SW5)
LB_F: L58.1, L59.1, L60.1, L61.1, L62.1, L63.1, L64.1, L65.1, L66.1, L67.1, L68.1, L69.1, L70.1, L71.1, U4.8 (SW6)
LB_G: L72.2, L73.2, L74.2, L75.2, L76.2, L77.2, L78.2, L79.2, L80.2, L81.2, L82.2, L83.2, U4.9 (SW7)
LB_H: L72.3, L73.3, L74.3, L75.3, L76.3, L77.3, L78.3, L79.3, L80.3, L81.3, L82.3, L83.3, U4.10 (SW8)
LB_I: L72.1, L73.1, L74.1, L75.1, L76.1, L77.1, L78.1, L79.1, L80.1, L81.1, L82.1, L83.1, U4.11 (SW9)
unnamed 52: C2.1, C3.1, C4.1, C5.1, C6.1, C7.1, C8.1, JP4.2 (C), U3.20 (PVCC), U3.29 (PVCC), U3.37 (AVCC), U3.38 (DVCC); also elsewhere on the board
unnamed 53: C10.1, C11.1, C12.1, C13.1, C14.1, C15.1, C16.1, JP8.2 (C), U4.20 (PVCC), U4.29 (PVCC), U4.37 (AVCC), U4.38 (DVCC); also elsewhere on the board
unnamed: D1.2, K1.2
unnamed: D2.2, K2.2
unnamed: D3.2, K3.2
unnamed: D4.2, K4.2
unnamed: D5.2, K5.2
unnamed: D6.2, K6.2
unnamed: D7.2, K7.2
unnamed: D8.2, K8.2
unnamed: D9.2, K9.2
unnamed: D10.2, K10.2
unnamed: D11.2, K11.2
unnamed: D12.2, K12.2
unnamed: D13.2, K13.2
unnamed: D14.2, K14.2
unnamed: D15.2, K15.2
unnamed: D16.2, K16.2
unnamed: D17.2, K17.2
unnamed: D18.2, K18.2
unnamed: D19.2, K19.2
unnamed: D20.2, K20.2
unnamed: D21.2, K21.2
unnamed: D22.2, K22.2
unnamed: D23.2, K23.2
unnamed: D24.2, K24.2
unnamed: D25.2, K25.2
unnamed: D26.2, K26.2
unnamed: D27.2, K27.2
unnamed: D28.2, K28.2
unnamed: D29.2, K29.2
unnamed: D30.2, K30.2
unnamed: D31.2, K31.2
unnamed: D32.2, K32.2
unnamed: D33.2, K33.2
unnamed: D34.2, K34.2
unnamed: D35.2, K35.2
unnamed: D36.2, K36.2
unnamed: D37.2, K37.2
unnamed: D38.2, K38.2
unnamed: D39.2, K39.2
unnamed: D40.2, K40.2
unnamed: D41.2, K41.2
unnamed: D42.2, K42.2
unnamed: D43.2, K43.2
unnamed: D44.2, K44.2
unnamed: D45.2, K45.2
unnamed: D46.2, K46.2
unnamed: D47.2, K47.2
unnamed: D48.2, K48.2
unnamed: D49.2, K49.2
unnamed: D50.2, K50.2
unnamed: D51.2, K51.2
unnamed: D52.2, K52.2
unnamed: D53.2, K53.2
unnamed: D54.2, K54.2
unnamed: D55.2, K55.2
unnamed: D56.2, K56.2
unnamed: D57.2, K57.2
unnamed: D58.2, K58.2
unnamed: D59.2, K59.2
unnamed: D60.2, K60.2
unnamed: D61.2, K61.2
unnamed: D62.2, K62.2
unnamed: D63.2, K63.2
unnamed: D64.2, K64.2
unnamed: D65.2, K65.2
unnamed: D66.2, K66.2
unnamed: D67.2, K67.2
unnamed: D68.2, K68.2
unnamed: D69.2, K69.2
unnamed: D70.2, K70.2
unnamed: D71.2, K71.2
unnamed: D72.2, K72.2
unnamed: D73.2, K73.2
unnamed: D74.2, K74.2
unnamed: D75.2, K75.2
unnamed: D76.2, K76.2
unnamed: D77.2, K77.2
unnamed: D78.2, K78.2
unnamed: D79.2, K79.2
unnamed: D80.2, K80.2
unnamed: D81.2, K81.2
unnamed: D82.2, K82.2
unnamed: D83.2, K83.2
unnamed: JP1.2 (C), U2.17 (A2)
unnamed: JP2.2 (C), U2.16 (A1)
unnamed: JP3.2 (C), U2.15 (A0)
unnamed 140: JP5.1 (A), U3.39 (VIO); also elsewhere on the board
unnamed 141: JP6.2 (B), U3.41 (SDA); also elsewhere on the board
unnamed 142: JP7.2 (B), U3.42 (SCL); also elsewhere on the board
unnamed 143: JP9.2 (B), U4.39 (VIO); also elsewhere on the board
unnamed 144: JP10.2 (B), U4.41 (SDA); also elsewhere on the board
unnamed 145: JP11.2 (B), U4.42 (SCL); also elsewhere on the board
unnamed: R6.2, U3.35 (RSET)
unnamed: R7.2, U4.35 (RSET)
unnamed: SW1.1 (A), TP3.1, U1.3 (En)
SCL: JP7.1 (A), JP11.1 (A), R2.1, U1.18 (PD0/SCL), U2.12 (SCK); also elsewhere on the board
SDA: JP6.1 (A), JP10.1 (A), R1.1, U1.19 (PD1/SDA), U2.13 (SDA); also elsewhere on the board
SDB: R4.2, U1.31 (PC6), U3.46 (~SDB), U4.46 (~SDB)
SYNC: U3.40 (SYNC), U4.40 (SYNC)
VBUS: JP4.1 (A), JP8.1 (A), U1.7 (VBUS); also elsewhere on the board
col0: K1.1, K16.1, K31.1, K45.1, K58.1, K72.1, TP2.1, U2.21 (GPA0)
col1: K2.1, K17.1, K32.1, K46.1, K59.1, K73.1, U2.22 (GPA1)
col2: K3.1, K18.1, K33.1, K47.1, K60.1, K74.1, U2.23 (GPA2)
col3: K4.1, K19.1, K34.1, K48.1, K61.1, K75.1, U2.24 (GPA3)
col4: K5.1, K20.1, K35.1, K49.1, K62.1, U2.25 (GPA4)
col5: K6.1, K21.1, K36.1, K50.1, K63.1, K76.1, U2.26 (GPA5)
col6: K7.1, K22.1, K37.1, K51.1, K64.1, U2.27 (GPA6)
col7: K8.1, K23.1, K38.1, K52.1, K65.1, K77.1, U2.28 (GPA7)
col8: K9.1, K24.1, K39.1, K53.1, K66.1, K78.1, U2.7 (GPB6)
col9: K10.1, K25.1, K40.1, K54.1, K67.1, K79.1, U2.6 (GPB5)
col10: K11.1, K26.1, K41.1, K55.1, K68.1, K80.1, U2.5 (GPB4)
col11: K12.1, K27.1, K42.1, K56.1, K69.1, K81.1, U2.4 (GPB3)
col12: K13.1, K28.1, K43.1, K70.1, K82.1, U2.3 (GPB2)
col13: K14.1, K29.1, K44.1, K57.1, U2.2 (GPB1)
col14: K15.1, K30.1, K71.1, K83.1, U2.1 (GPB0)
row0: D1.1, D2.1, D3.1, D4.1, D5.1, D6.1, D7.1, D8.1, D9.1, D10.1, D11.1, D12.1, D13.1, D14.1, D15.1, U1.41 (PF0)
row1: D16.1, D17.1, D18.1, D19.1, D20.1, D21.1, D22.1, D23.1, D24.1, D25.1, D26.1, D27.1, D28.1, D29.1, D30.1, U1.40 (PF1)
row2: D31.1, D32.1, D33.1, D34.1, D35.1, D36.1, D37.1, D38.1, D39.1, D40.1, D41.1, D42.1, D43.1, D44.1, U1.39 (PF4)
row3: D45.1, D46.1, D47.1, D48.1, D49.1, D50.1, D51.1, D52.1, D53.1, D54.1, D55.1, D56.1, D57.1, U1.38 (PF5)
row4: D58.1, D59.1, D60.1, D61.1, D62.1, D63.1, D64.1, D65.1, D66.1, D67.1, D68.1, D69.1, D70.1, D71.1, U1.37 (PF6)
row5: D72.1, D73.1, D74.1, D75.1, D76.1, D77.1, D78.1, D79.1, D80.1, D81.1, D82.1, D83.1, U1.36 (PF7)

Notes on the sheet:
LEDs
Key Matrix
nts: use tantalum capacitor here to avoid noise
slave 1 addr 1010011X
master addr 1010000X
3V3 power slide switch
AREF uses internal 3V3 by default
addr 0100000X X is R/W bit
SPI pins used by Bluefruit
Adafruit 32u4 Feather Bluefruit LE dev board
i2c I/O expander
i2c LED matrix driver
(reverse-mount SMD common-anode RGB)
VIO on 3V3 to talk with mcu AVCC/DVCC/PVCC on VBUS (5V plugged, VBAT unplugged)

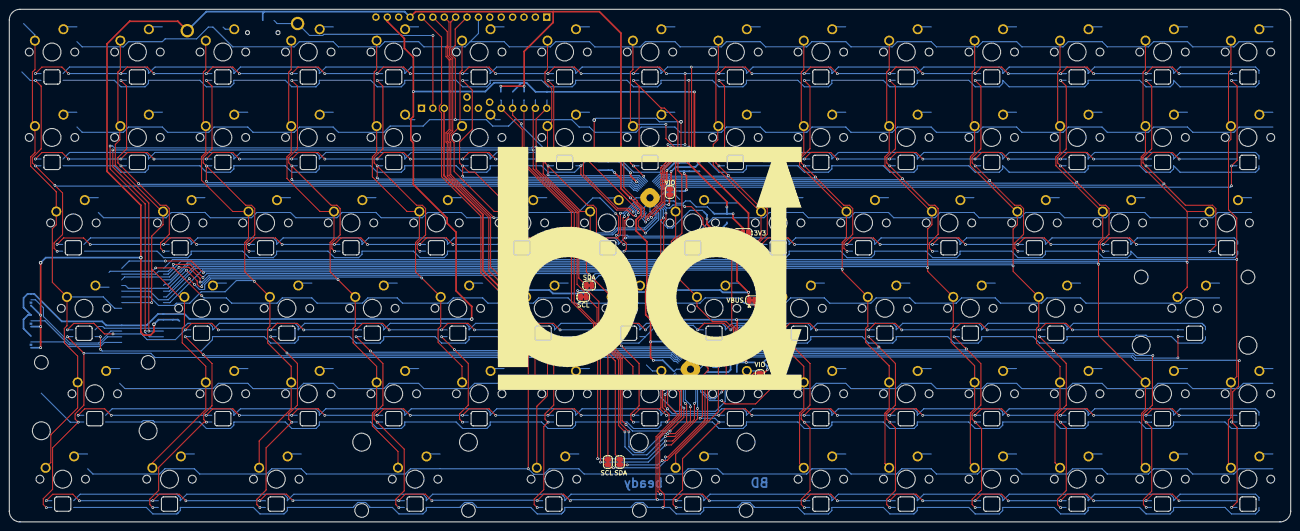
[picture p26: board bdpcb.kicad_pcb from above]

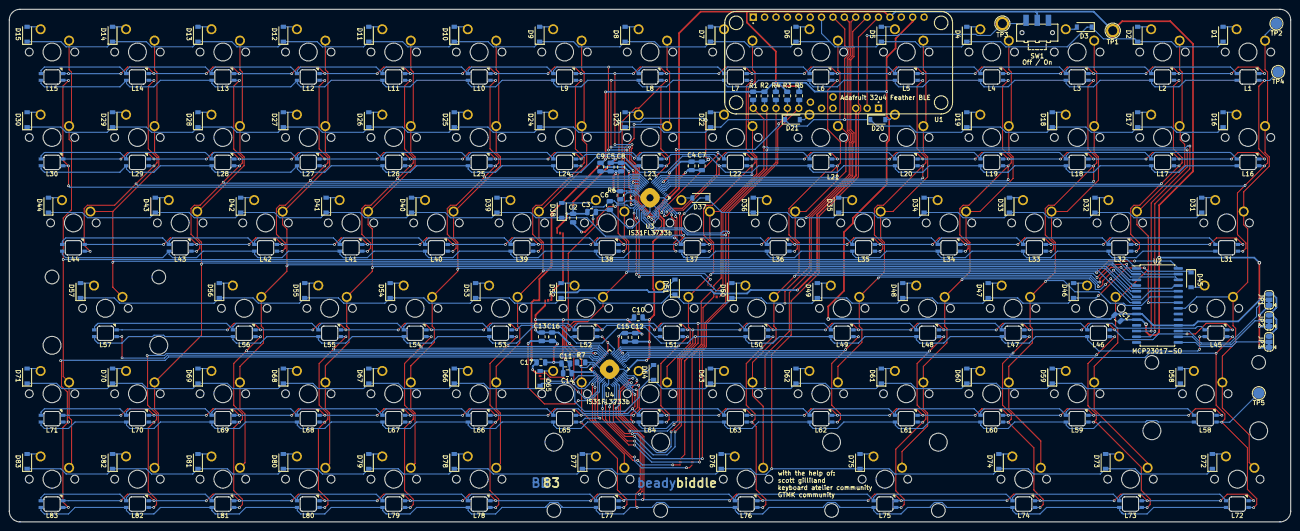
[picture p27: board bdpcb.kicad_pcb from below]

Board: 2 copper layers, 285.8 x 114.3 mm, 295 parts (203 on the bottom side), 175 nets.

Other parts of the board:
3V3: 13_bridge; SolderJumper-3_P1.3mm_Bridged12_RoundedPad1.0x1.5mm
G1: LOGO; BD_logo
SCL: SolderJumper_2_Bridged; SolderJumper-2_P1.3mm_Bridged_RoundedPad1.0x1.5mm
SCL#2: SolderJumper_2_Bridged; SolderJumper-2_P1.3mm_Bridged_RoundedPad1.0x1.5mm
SDA: SolderJumper_2_Bridged; SolderJumper-2_P1.3mm_Bridged_RoundedPad1.0x1.5mm
SDA#2: SolderJumper_2_Bridged; SolderJumper-2_P1.3mm_Bridged_RoundedPad1.0x1.5mm
VBUS: 13_bridge; SolderJumper-3_P1.3mm_Bridged12_RoundedPad1.0x1.5mm
VIO: SolderJumper_2_Bridged; SolderJumper-2_P1.3mm_Bridged_RoundedPad1.0x1.5mm
VIO#2: SolderJumper_2_Bridged; SolderJumper-2_P1.3mm_Bridged_RoundedPad1.0x1.5mm

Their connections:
+3V3: 3V3.3, VBUS.3, VIO.1, VIO#2.2; also elsewhere on the board
unnamed 52: 3V3.2; also elsewhere on the board
unnamed 53: VBUS.2; also elsewhere on the board
unnamed 140: VIO#2.1; also elsewhere on the board
unnamed 141: SDA#2.2; also elsewhere on the board
unnamed 142: SCL#2.2; also elsewhere on the board
unnamed 143: VIO.2; also elsewhere on the board
unnamed 144: SDA.2; also elsewhere on the board
unnamed 145: SCL.2; also elsewhere on the board
SCL: SCL.1, SCL#2.1; also elsewhere on the board
SDA: SDA.1, SDA#2.1; also elsewhere on the board
VBUS: 3V3.1, VBUS.1; also elsewhere on the board

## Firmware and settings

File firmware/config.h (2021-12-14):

// Copyright 2021 David Desrochers (@beadybiddle)
// SPDX-License-Identifier: GPL-2.0-or-later

#pragma once

#include "config_common.h"

/* USB Device descriptor parameter */
#define VENDOR_ID    0xBE4D
#define PRODUCT_ID   0xBD83
#define DEVICE_VER   0x0001
#define MANUFACTURER beadybiddle
#define PRODUCT      bd83

/* matrix deets */
#define MATRIX_ROWS 6
#define MATRIX_COLS 15
#define MATRIX_ROW_PINS_MCU { F0, F1, F4, F5, F6, F7}
#define MATRIX_COL_PINS_MCP { A0, A1, A2, A3, A4, A5, A6, A7, B6, B5, B4, B3, B2, B1, B0}
#define MATRIX_ROW_PINS { F0, F1, F4, F5, F6, F7}
#define MATRIX_COL_PINS { A1, A1, A1, A1, A1, A1, A1, A1, A1, A1, A1, A1, A1, A1, A1} // just placeholder pins
// #define MATRIX_IO_DELAY 30
#define DIODE_DIRECTION COL2ROW

/* Debounce reduces chatter (unintended double-presses) - set 0 if debouncing is not needed */
#define DEBOUNCE 5

/* double tap to sticky layer via TT */
#define TAPPING_TOGGLE 2

/* disable these deprecated features by default */
#define NO_ACTION_MACRO
#define NO_ACTION_FUNCTION

// /* Bootmagic Lite key configuration */
// //#define BOOTMAGIC_LITE_ROW 0
// //#define BOOTMAGIC_LITE_COLUMN 0

#ifdef RGB_MATRIX_ENABLE
	/* RGB driving */
	#define DRIVER_COUNT 2
	// #define DRIVER_COUNT 1
	#define DRIVER_1_LED_TOTAL 44
	// #define DRIVER_LED_TOTAL (DRIVER_1_LED_TOTAL)
	#define DRIVER_2_LED_TOTAL 39
	#define DRIVER_LED_TOTAL (DRIVER_1_LED_TOTAL + DRIVER_2_LED_TOTAL)
	// 00 <-> GND
	// 01 <-> SCL
	// 10 <-> SDA
	// 11 <-> VCC
	// address as 0b101(ADDR2)(ADDR1)
	#define DRIVER_ADDR_1 0b1010000 // master
	#define DRIVER_ADDR_2 0b1010011 // slave 1
	#define DRIVER_SYNC_1 01 // sync clock master
	#define DRIVER_SYNC_2 10 // sync clock slave

	#define RGB_MATRIX_LED_PROCESS_LIMIT (DRIVER_LED_TOTAL + 4) / 5
	#define RGB_MATRIX_LED_FLUSH_LIMIT 16 // 60 Hz equivalent
	#define RGB_DISABLE_TIMEOUT 600000 // 10 minute timeout
	#define RGB_DISABLE_WHEN_USB_SUSPENDED
	#define RGBLIGHT_SLEEP // sleep when host sleeps
	#define RGB_MATRIX_MAXIMUM_BRIGHTNESS 200 // to limit power consumption
	#define RGB_MATRIX_KEYPRESSES
	#define RGB_MATRIX_FRAMEBUFFER_EFFECTS

	/* RGB startup defaults */
	#define RGB_MATRIX_STARTUP_MODE RGB_MATRIX_SOLID_REACTIVE
	#define RGB_MATRIX_STARTUP_HUE 90 // goldish
	#define RGB_MATRIX_STARTUP_SAT 225
	#define RGB_MATRIX_STARTUP_VAL RGB_MATRIX_MAXIMUM_BRIGHTNESS
	#define RGB_MATRIX_STARTUP_SPD 127

	// #define RGBLIGHT_HUE_STEP 10
	// #define RGBLIGHT_SAT_STEP 17
	// #define RGBLIGHT_VAL_STEP 17

	// TODO RGB COLOR LAYERS

	#define ENABLE_RGB_MATRIX_ALPHAS_MODS
	#define ENABLE_RGB_MATRIX_BREATHING
	#define ENABLE_RGB_MATRIX_CYCLE_ALL
	#define ENABLE_RGB_MATRIX_TYPING_HEATMAP
	#define ENABLE_RGB_MATRIX_DIGITAL_RAIN
	#define ENABLE_RGB_MATRIX_SOLID_REACTIVE_SIMPLE
	#define ENABLE_RGB_MATRIX_SOLID_REACTIVE
	#define ENABLE_RGB_MATRIX_SOLID_REACTIVE_WIDE
	#define ENABLE_RGB_MATRIX_SPLASH
	#define ENABLE_RGB_MATRIX_MULTISPLASH
	#define ENABLE_RGB_MATRIX_SOLID_SPLASH
	#define ENABLE_RGB_MATRIX_SOLID_MULTISPLASH
#endif

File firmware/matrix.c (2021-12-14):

/*
Copyright 2013 Oleg Kostyuk <cub.uanic@gmail.com>
          2020 Pierre Chevalier <pierrechevalier83@gmail.com>

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
You should have received a copy of the GNU General Public License
along with this program.  If not, see <http://www.gnu.org/licenses/>.
*/

/*
 * This code was heavily inspired by the ergodox_ez keymap, and modernized
 * to take advantage of the quantum.h microcontroller agnostics gpio control
 * abstractions and use the macros defined in config.h for the wiring as opposed
 * to repeating that information all over the place.
 */

#include QMK_KEYBOARD_H
#include "i2c_master.h"
#include "print.h"

extern i2c_status_t mcp23017_status;
#define I2C_TIMEOUT 1000
#define I2C_WRITE   0x00
#define I2C_READ    0x01

// | 0  | 1  | 0  | 0  | A2 | A1 | A0 |
// | 0  | 1  | 0  | 0  | 0  | 0  | 0  |
#define I2C_ADDR       0b0100000
#define I2C_ADDR_WRITE ((I2C_ADDR << 1) | I2C_WRITE)
#define I2C_ADDR_READ  ((I2C_ADDR << 1) | I2C_READ )
#define IODIRA         0x00 // i/o direction register
#define IODIRB         0x01
#define GPPUA          0x0C // GPIO pull-up resistor register
#define GPPUB          0x0D
#define GPIOA          0x12 // general purpose i/o port register (write modifies OLAT)
#define GPIOB          0x13
#define OLATA          0x14 // output latch register
#define OLATB          0x15

bool i2c_initialized = 0;
i2c_status_t mcp23017_status = I2C_ADDR;

uint8_t init_mcp23017(void) {
    print("starting init\n");
    mcp23017_status = I2C_ADDR;

    // I2C subsystem
    if (i2c_initialized == 0) {
        i2c_init(); // on pins D(1,0)
        i2c_initialized = true;
        wait_ms(I2C_TIMEOUT);
    }

    // set pin direction
    // unused/input : 1
    // driving      : 0
    uint8_t buf[] = {IODIRA, 0b11111111, 0b11111111};
    dprint("before transmit\n");
    mcp23017_status = i2c_transmit(I2C_ADDR_WRITE, buf, sizeof(buf), I2C_TIMEOUT);
    xprintf("after iodir transmit %x\n", mcp23017_status);
    if (!mcp23017_status) {
        // set pull-up
        uint8_t pullup_buf[] = {GPPUA, 0b11111111, 0b11111111};
        mcp23017_status = i2c_transmit(I2C_ADDR_WRITE, pullup_buf, sizeof(pullup_buf), I2C_TIMEOUT);
        uprintf("after pullup transmit %x\n", mcp23017_status);
    }
    return mcp23017_status;
}

/* matrix state(1:on, 0:off) */
static matrix_row_t matrix[MATRIX_ROWS];  // debounced values

static matrix_row_t read_cols(uint8_t row);
static uint8_t      reverse_byte(uint8_t byte);
static void         unselect_rows(void);
static void         select_row(uint8_t row);

static uint8_t mcp23017_reset_loop;

void matrix_init_custom(void) {
    debug_enable = true;
    debug_matrix = true;
    dprint("matrix_init_custom\n");

    mcp23017_status = init_mcp23017();
    unselect_rows();

    // initialize matrix state: all keys off
    for (uint8_t i = 0; i < MATRIX_ROWS; i++) {
        matrix[i] = 0;
    }
}

// needed for functioning after suspend/wakeup
void matrix_power_up(void) {
    mcp23017_status = init_mcp23017();

    unselect_rows();

    // initialize matrix state: all keys off
    for (uint8_t i = 0; i < MATRIX_ROWS; i++) {
        matrix[i] = 0;
    }
}

// Reads and stores a row, returning
// whether a change occurred.
static inline bool store_matrix_row(matrix_row_t current_matrix[], uint8_t index) {
    matrix_row_t temp = read_cols(index);
    if (current_matrix[index] != temp) {
        current_matrix[index] = temp;
        return true;
    }
    return false;
}

bool matrix_scan_custom(matrix_row_t current_matrix[]) {
    if (mcp23017_status) {  // if there was an error
        if (++mcp23017_reset_loop == 0) {
            dprint("trying to reset mcp23017\n");
            mcp23017_status = init_mcp23017();
            if (mcp23017_status) {
                dprint("expander? i hardly know 'er!\n");
            } else {
                dprint("expander attached\n");
            }
        }
    }

    bool changed = false;
    for (uint8_t i = 0; i < MATRIX_ROWS; i++) {
        select_row(i);

        changed |= store_matrix_row(current_matrix, i);

        unselect_rows();
    }
    return changed;
}

static matrix_row_t read_cols(uint8_t row) {
    // matrix_io_delay();
    if (mcp23017_status) {  // if there was an error
        return 0;
    } else {
        uint8_t buf[] = {GPIOA};
        mcp23017_status = i2c_transmit(I2C_ADDR_WRITE, buf, sizeof(buf), I2C_TIMEOUT);
        uint8_t data[] = {0, 0}; // { GPIOB, GPIOA }
        if (!mcp23017_status) {
            mcp23017_status = i2c_receive(I2C_ADDR_READ, &data[1], sizeof(data[1]), I2C_TIMEOUT);
        }

        uint8_t buf2[] = {GPIOB};
        mcp23017_status = i2c_transmit(I2C_ADDR_WRITE, buf2, sizeof(buf2), I2C_TIMEOUT);
        if (!mcp23017_status) {
            mcp23017_status = i2c_receive(I2C_ADDR_READ, data, sizeof(data[0]), I2C_TIMEOUT);
        }

        uint16_t current_row_value = reverse_byte(~(data[0]) << 1);
        current_row_value <<= 8;
        current_row_value |= ~(data[1]) & 0x00FF;

        return current_row_value;
    }
}

static uint8_t reverse_byte(uint8_t byte) {
    uint8_t etyb = 0;
    for (int i = 0; i < 8; i++) {
        if (byte & (1 << i)) {
           etyb |= 1 << (7 - i);  
        }
    }
    return etyb;
}

static void unselect_rows(void) {
    pin_t matrix_row_pins_mcu[MATRIX_ROWS] = MATRIX_ROW_PINS_MCU;
    for (int pin_index = 0; pin_index < MATRIX_ROWS; pin_index++) {
        pin_t pin = matrix_row_pins_mcu[pin_index];
        setPinInput(pin);
        writePinLow(pin);
    }
}

static void select_row(uint8_t row) {
    pin_t matrix_row_pins_mcu[MATRIX_ROWS] = MATRIX_ROW_PINS_MCU;
    pin_t pin = matrix_row_pins_mcu[row];
    setPinOutput(pin);
    writePinLow(pin);
}

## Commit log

2021-11-14 removed mcu and BLE and power stuff
    [bdpcb.sch]
2021-11-14 IO expander not integrated yet
    [bdpcb.sch]
2021-11-18 scott's suggestions and new LED symbol/footprints
    [bdpcb.sch]
2021-11-18 starting pcb
    [bdpcb.kicad_pcb, bdpcb.sch]
2021-11-18 changed feather footprint and moving LEDS
    [bdpcb.kicad_pcb]
2021-11-18 LEDs placed
    [bdpcb.kicad_pcb]
2021-11-18 just diodes left to move, then fine tune and trace
    [bdpcb.kicad_pcb]
2021-11-18 diodes roughly placed
    [bdpcb.kicad_pcb]
2021-11-18 reverse stabs and outer edge cuts
    [bdpcb.kicad_pcb]
2021-11-18 square LED cutouts
    [bdpcb.kicad_pcb]
2021-11-18 beginning diode positioning
    [bdpcb.kicad_pcb]
2021-11-18 rounded rectangle holes and starting diode traces
    [bdpcb.kicad_pcb]
2021-11-18 two rows of diodes
    [bdpcb.kicad_pcb]
2021-11-18 more diode routing
    [bdpcb.kicad_pcb]
2021-11-19 good progress on traces
    [bdpcb.kicad_pcb]
2021-11-19 getting there on traces
    [bdpcb.kicad_pcb]
2021-11-19 fixed feather footprint pinout to match symbol
    [bdpcb.kicad_pcb, bdpcb.sch]
2021-11-19 bottom rows, still cant track to qfn pins
    [bdpcb.kicad_pcb]
2021-11-19 random stuff; power switch, some cols, re-added accidentally deleted key
    [bdpcb.kicad_pcb]
2021-11-19 tidied vertical traces and making superhighway
    [bdpcb.kicad_pcb]
2021-11-19 doing LED cols
    [bdpcb.kicad_pcb]
2021-11-20 tightening spacing on vias and traces, about to redo it all probs
    [bdpcb.kicad_pcb]
2021-11-20 deleted all traces and vias
    [bdpcb.kicad_pcb]
2021-11-21 reoriented diodes
    [bdpcb.kicad_pcb]
2021-11-22 better row/col tracks starting
    [bdpcb.kicad_pcb]
2021-11-22 almost there with row/col tracks
    [bdpcb.kicad_pcb]
2021-11-23 4.7k i2c pullups and laying row tracks
    [bdpcb.kicad_pcb, bdpcb.sch]
2021-11-23 left half tracks down!
    [bdpcb.kicad_pcb]
2021-11-23 rows and cols done
    [bdpcb.kicad_pcb]
2021-11-23 added silkscreen hole on keysw pth front
    [bdpcb.kicad_pcb]
2021-11-23 idk how im gonna get all these wires into these chips
    [bdpcb.kicad_pcb]
2021-11-23 re-added feather VBUS pin7
    [bdpcb.kicad_pcb]
2021-11-23 figured out how to change power track width
    [bdpcb.kicad_pcb, bdpcb.sch]
2021-11-23 added VBUS/3V3 bridges for driver power
    [bdpcb.kicad_pcb, bdpcb.sch]
2021-11-23 updated LED footprint
    [bdpcb.kicad_pcb]
2021-11-23 removed led driver addr jumper bridges
    [bdpcb.kicad_pcb, bdpcb.sch]
2021-11-23 i/o expander routed
    [bdpcb.kicad_pcb]
2021-11-23 reannotated and connected ic grounds
    [bdpcb.kicad_pcb]
2021-11-24 two ICs down, one to go
    [bdpcb.kicad_pcb]
2021-11-24 just caps and a jumper left
    [bdpcb.kicad_pcb]
2021-11-24 everything routed!
    [bdpcb.kicad_pcb]
2021-11-24 actually done with tracing now; DRC passes
    [bdpcb.kicad_pcb]
2021-11-24 text sizing up to spec + new labels
    [bdpcb.kicad_pcb, bdpcb.sch]
2021-11-24 fancy author tag
    [bdpcb.kicad_pcb]
2021-11-24 logo silkscreen
    [bdpcb.kicad_pcb]
2021-11-24 thermal vias and fixed jumper silks
    [bdpcb.kicad_pcb]
2021-11-24 driver thermal vias and gerber plot
    [bdpcb-B_Cu.gbr, bdpcb-B_Mask.gbr, bdpcb-B_Paste.gbr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]
2021-11-24 gerber folder
    [bdpcb-B_Cu.gbr, bdpcb-B_Mask.gbr, bdpcb-B_Paste.gbr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]
2021-11-24 drill files
    [bdpcb-NPTH.drl, bdpcb-PTH.drl]
2021-11-30 groundwork for LEDs
2021-12-01 idk what im doing with LED and MCP i2c
2021-12-11 figuring out RGB framework from ktype
2021-12-11 led config layouts
2021-12-12 reduced further, flashes now but doesn't work
    [config.h, matrix.c]
2021-12-14 fixed RGB physical locations
    [config.h]
2021-12-14 plate image

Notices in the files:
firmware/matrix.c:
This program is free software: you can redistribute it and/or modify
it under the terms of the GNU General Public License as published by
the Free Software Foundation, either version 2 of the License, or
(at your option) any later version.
